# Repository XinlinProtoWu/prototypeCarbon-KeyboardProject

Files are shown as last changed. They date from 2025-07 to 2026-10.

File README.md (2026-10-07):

# Prototype Carbon — A Custom 65% Mechanical Keyboard

A 65% mechanical keyboard I designed, built, and programmed from scratch.
It has 67 keys, split 3u spacebars, a gasket-mounted acrylic case, hot-swap sockets,
per-key RGB, and QMK firmware with VIA remapping.

**Watch the demo:**

Watch Video (https://www.youtube.com/watch?v=WMbd48JGXQo&ab_channel=XinlinWu)

---

## Project Overview

Prototype Carbon went through the whole design process, from requirements and a rough
architecture down to the schematic, board layout, case, firmware, and finally a working keyboard.

| System | Spec |
|---|---|
| Layout | 65%, 67 keys, standard stagger |
| Spacebars | 2x 3u split spacebars |
| Switch matrix | 5 rows x 15 columns, COL2ROW diodes |
| MCU | ATmega32u4-AU (QFP-44) at 16 MHz |
| Connectivity | USB-C |
| Firmware | QMK with VIA remapping enabled |
| RGB | 75x WS2812B LEDs (67 per-key + 8 underglow) on pin B0 |
| Switches | 67x Kailh hot-swap sockets |
| Mounting | Gasket mount, layered acrylic shell |
| Diodes | 67x SOD-123F |

---

## Design Requirements

| ID | Requirement |
|---|---|
| R1 | 65% form factor with a dedicated arrow cluster and nav column |
| R2 | Two 3u split spacebars for extra thumb inputs |
| R3 | Fully hot-swappable, so switches can be changed without soldering |
| R4 | Per-key RGB backlighting plus underglow on a single data line |
| R5 | USB-C connectivity and standard HID, no drivers needed |
| R6 | Keys remappable live through VIA |
| R7 | A soft, gasket-mounted typing feel in a stacked acrylic case |
| R8 | A function layer with F1–F12 and RGB controls |

---

## System Architecture

```
+--------------------------------------------------------------------------+
|                                HOST (PC)                                  |
|                         USB-C  /  HID keyboard                            |
+------------------------------------+-------------------------------------+
                                     | USB
+------------------------------------v-------------------------------------+
|  ATmega32u4-AU at 16 MHz            +-----------------------------------+ |
|  QMK firmware (+VIA)                |  RGB matrix (WS2812B, pin B0)     | |
|                                     |  75 LEDs: 67 per-key + 8 underglow| |
|  +---------------+                  +-----------------------------------+ |
|  | 5x15 switch   |                                                     | |
|  | matrix        |  <- 67x Kailh hot-swap sockets + SOD-123F diodes    | |
|  | (COL2ROW)     |                                                     | |
|  +---------------+                                                     | |
|   (EC11 rotary encoder is routed but not usable, see Known Issues)      | |
+--------------------------------------------------------------------------+
```

**Signal flow:** a key press closes a switch in the matrix, the MCU scans the rows and columns
(COL2ROW), QMK debounces the input and maps it to a keycode, then sends a USB HID report to the
host. At the same time, QMK's RGB matrix drives all 75 WS2812B LEDs over a single data pin.

---

## Systems Design Process

This was an iterative process. Each step produced the files that fed into the next one, and
testing fed problems back into earlier steps.

```mermaid
flowchart TD
    A[1. Requirements & Concept] --> B[2. Electrical Design / Schematic]
    B --> C[3. PCB Design & Layout]
    A --> D[4. Mechanical Design / Case, Plate, Gasket]
    C --> E[5. Firmware Design / QMK & VIA]
    D --> F[6. Integration & Assembly]
    E --> F
    F --> G[7. Verification & Testing]
    G -->|issues found| B
    G --> H[8. Iteration & Lessons Learned]
```

### Phase 1 — Requirements & Concept

I started with the layout, deciding where every key sits and how big the modifiers and spacebars
should be, before committing to any hardware.

- **Layout spec (KLE):** [layout.txt](./layout.txt) — the 67-key 65% layout with split 3u spacebars
- **Layout model:** [protocarbon.json](./protocarbon.json) — keyboard-layout-editor JSON
- **Keymap matrix:** [prototypeCarbonVIA.json](./prototypeCarbonVIA.json) — the 5x15 matrix and VIA layout

### Phase 2 — Electrical Design (Schematic)

Next came the schematic: an ATmega32u4 with a 16 MHz crystal, USB-C, the COL2ROW switch matrix,
the per-key RGB chain, and the usual decoupling caps.

- **Schematic:** [SCH_prototypeCarbon_2025-07-03.json](./SCH_prototypeCarbon_2025-07-03.json)
- **Bill of materials:** [BOM_prototypeCarbon_2025-07-03.csv](./BOM_prototypeCarbon_2025-07-03.csv)
- **Shopping list:** [prototypeCarbonShoppingList - BOM_prototypeCarbon_2025-07-03.csv](./prototypeCarbonShoppingList%20-%20BOM_prototypeCarbon_2025-07-03.csv)

### Phase 3 — PCB Design & Layout

Then I routed the board, placed the hot-swap sockets and per-key LEDs, and exported the files
needed for manufacturing.

- **PCB design:** [PCB_PCB_prototypeCarbon_2025-07-03.json](./PCB_PCB_prototypeCarbon_2025-07-03.json)
- **PCB outline (DXF):** [PCB_prototypeCarbon_2025-07-05.dxf](./PCB_prototypeCarbon_2025-07-05.dxf)
- **PCB outline, revised:** [PCB_prototypeCarbon_2025-07-05 gai.dxf](./PCB_prototypeCarbon_2025-07-05%20gai.dxf)
- **Gerber files (fabrication):** [Gerber_prototypeCarbon_PCB_prototypeCarbon_2025-07-03.zip](./Gerber_prototypeCarbon_PCB_prototypeCarbon_2025-07-03.zip)

### Phase 4 — Mechanical Design (Case, Plate & Gasket)

The case came next: a gasket-mounted stack of laser-cut acrylic layers sized to match the PCB.

- **Acrylic shell stack (DWG):** [prototypeCarbonGasketShell.dwg](./prototypeCarbonGasketShell.dwg)
- **Acrylic plates (DWG):** [prototypeCarbonAcrylicPlates.dwg](./prototypeCarbonAcrylicPlates.dwg)
- **Stack drawing (DWG):** [stack.dwg](./stack.dwg)
- **Switch plate (DWG):** [plate1.dwg](./plate1.dwg) / (DXF) [plate1.dxf](./plate1.dxf)
- **Gasket (DWG):** [gasket.dwg](./gasket.dwg) / [prototypeCarbonGasket.dwg](./prototypeCarbonGasket.dwg)

### Phase 5 — Firmware Design (QMK + VIA)

With the hardware designed, I wrote the QMK firmware: matrix pins, COL2ROW, the WS2812B RGB
matrix, and a function layer, plus VIA support so keys can be remapped without reflashing.

- **Firmware directory:** [qmk_firmware/keyboards/prototypeCarbon](./qmk_firmware/keyboards/prototypeCarbon)
- **Hardware config:** `config.h`, `rules.mk` (matrix pins, RGB, VIA)
- **Keymaps:** `keymaps/default/keymap.c` and `keymaps/VIA/keymap.c`
- **Layer-2 keybind reference:** [layer2keybind.JPG](./layer2keybind.JPG)

### Phase 6 — Integration & Assembly

Assembly meant soldering the SMD parts (MCU, diodes, caps, LEDs, USB-C), snapping in the hot-swap
sockets, and bolting the case together.

- 24x M2 x 4 mm screws
- 12x M2 x 14 mm double-headed copper standoffs

### Phase 7 — Verification & Testing

I flashed the firmware and checked the whole system end to end.

- Passed: key matrix scan across all 67 keys
- Passed: RGB chain (67 per-key + 8 underglow) on a single data pin
- Passed: VIA detection and live remapping
- Failed: EC11 rotary encoder — see Known Issues below

### Phase 8 — Iteration & Lessons Learned

Testing caught a routing mistake on the rotary encoder (EC11 wired to AREF). I documented it,
isolated it, and worked around it. A proper fix would need a schematic and PCB re-spin.

---

## How to Build This Keyboard

1. **Print the PCB** — [Gerber_prototypeCarbon_PCB_prototypeCarbon_2025-07-03.zip](./Gerber_prototypeCarbon_PCB_prototypeCarbon_2025-07-03.zip)
2. **Print the case and plates** — [prototypeCarbonGasketShell.dwg](./prototypeCarbonGasketShell.dwg) and [gasket.dwg](./gasket.dwg)
3. **Order the electrical components** — [BOM_prototypeCarbon_2025-07-03.csv](./BOM_prototypeCarbon_2025-07-03.csv), plus:
   - 1x ATmega32u4AU microcontroller
   - 67x Kailh hot-swap sockets
   - 67x 6028RGBC-WS2812B RGB LEDs
4. **Buy the keyboard parts** — 67x switches, 67x keycaps, 24x M2 x 4 mm screws, 12x M2 x 14 mm standoffs
5. **Assemble** — keep the PCB in front of you while soldering, and double-check the LED and MCU pin orientation
6. **Compile the firmware** — use QMK_MSYS in [qmk_firmware/keyboards/prototypeCarbon](./qmk_firmware/keyboards/prototypeCarbon)
7. **Flash** — upload the compiled firmware with QMK Toolbox
8. **Configure in VIA** — load [prototypeCarbonVIA.json](./prototypeCarbonVIA.json) to view or remap the keymap

---

## Known Issues

**EC11 rotary encoder pin error**

The EC11 rotary encoder is not wired correctly on the PCB — one of its pins connects to the AREF
pin on the ATmega32u4AU. Don't install it unless you fix this in hardware first; use a regular
hot-swap socket in its place for now.

---

## Repository Structure

| Path | Purpose |
|---|---|
| `layout.txt` / `protocarbon.json` | Layout concept (KLE) |
| `SCH_prototypeCarbon_2025-07-03.json` | Schematic |
| `PCB_PCB_prototypeCarbon_2025-07-03.json` | PCB layout |
| `Gerber_*.zip` | PCB fabrication files |
| `*.dwg` / `*.dxf` | Case, plates, gasket (mechanical) |
| `BOM_*.csv` | Bill of materials |
| `prototypeCarbonVIA.json` | VIA keymap definition |
| `qmk_firmware/keyboards/prototypeCarbon/` | QMK firmware |

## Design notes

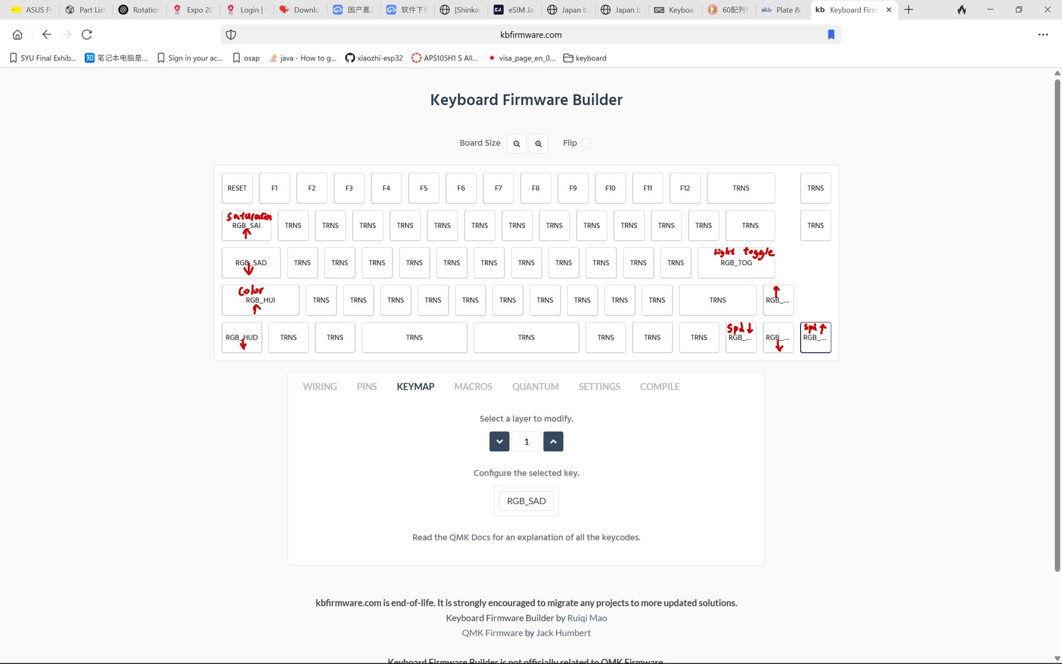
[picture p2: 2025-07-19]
layer2keybind.JPG

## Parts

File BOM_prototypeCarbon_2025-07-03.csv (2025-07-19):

ID | Name | Designator | Footprint | Quantity
1 | 1uF | C1 | C0805 | 1
2 | 20pF | C2,C3 | C0805 | 2
3 | 100nF | C9,C10,C11,C12,C13,C14,C15,C16,C17,C18,C19,C20,C21,C22,C23,C24,C25,C26,C27,C28,C29,C30,C31,C32,C33,C34,C35,C36,C37,C38,C39,C40,C41,C42,C43,C44,C45,C46,C47,C48,C49,C50,C51,C52,C53,C54,C55,C56,C57,C58,C59,C60,C61,C62,C63,C64,C65,C66,C67,C68,C69,C70,C71,C72,C73,C74,C75,C76,C77,C78,C79,C80,C81,C82,C84,C7,C6,C5,C4 | C0805 | 79
4 | SOD4002-SH | D1,D2,D3,D4,D5,D6,D7,D8,D9,D10,D11,D12,D13,D14,D15,D16,D17,D18,D19,D20,D21,D22,D23,D24,D25,D26,D27,D28,D29,D30,D31,D32,D33,D34,D35,D36,D37,D38,D39,D40,D41,D42,D43,D44,D45,D46,D47,D48,D49,D50,D51,D52,D53,D54,D55,D56,D57,D58,D59,D60,D61,D62,D63,D64,D65,D66,D67 | SOD-123F_L2.8-W1.8-LS3.7-RD | 67
5 | Switch3x4x2 | KEY1 | SW-SMD_L4.0-W2.9-LS5.0 | 1
6 | 10kΩ | R1,R2 | R0805 | 2
7 | 22Ω | R3,R4 | R0805 | 2
8 | ATMEGA32U4-AU | U1 | QFP-44_L10.0-W10.0-P0.80-LS13.2-BL | 1
9 | 16MHz | X1 | OSC-SMD_2P-L5.0-W3.2 | 1
10 | WS2812B-3528 | U2,U3,U4,U5,U6,U7,U8,U9 | WS2812B-3528 | 8
11 | TYPE-C-31-M-12 | USBC1 | USB-C_SMD-TYPE-C-31-M-12 | 1
12 | 470nF | C8 | C0805 | 1
13 | EC11E15244G1 | SW68 | SW-TH_EC11E15244G1GAI | 1

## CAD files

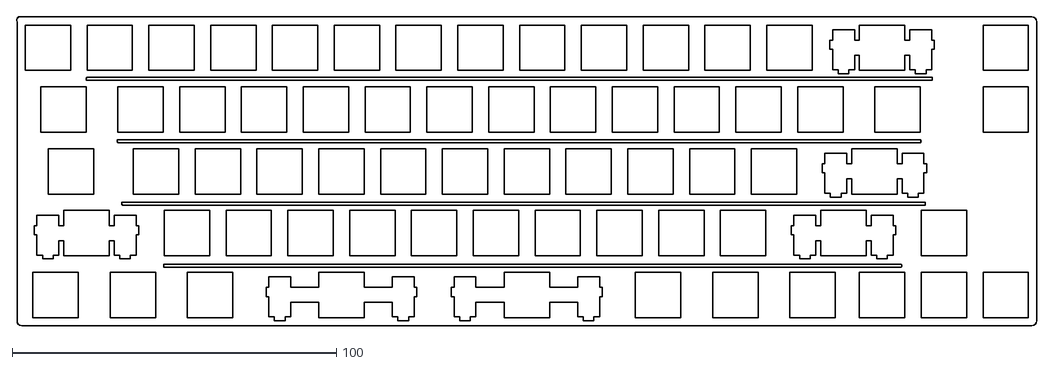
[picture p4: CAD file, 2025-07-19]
plate1.dxf
314.5 x 95.5

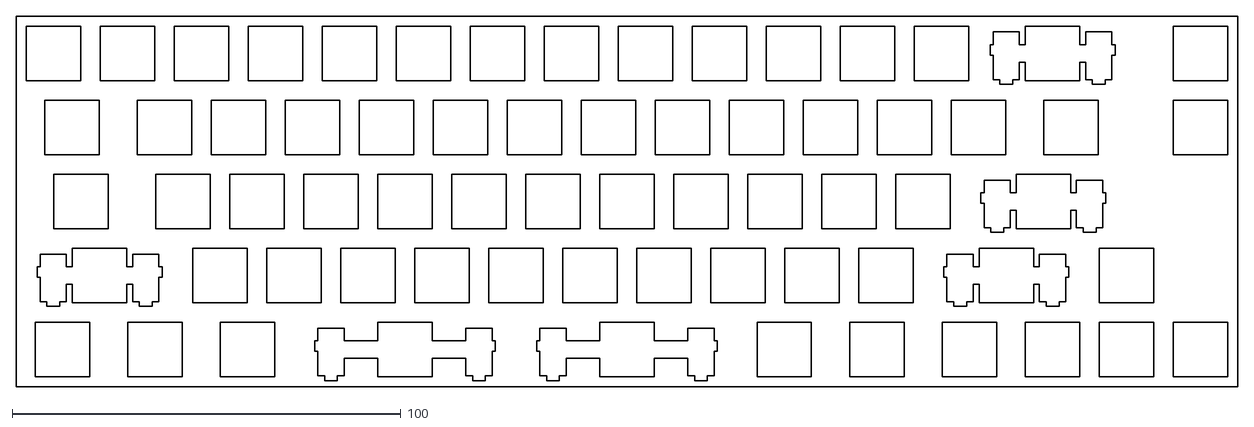
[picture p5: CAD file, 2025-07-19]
plate.dxf
314.3 x 95.2

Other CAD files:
prototypeCarbonGasket.dwg
PCB_prototypeCarbon_2025-07-05 gai.dxf
stack.dwg
plate1_recover.dwg
gasket.dwg
PCB_prototypeCarbon_2025-07-05.dxf
prototypeCarbonAcrylicPlates.dwg
prototypeCarbonGasketShell.dwg
plate1.dwg

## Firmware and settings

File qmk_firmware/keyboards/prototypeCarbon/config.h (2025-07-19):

#ifndef CONFIG_H
#define CONFIG_H

#include "config_common.h"

/* USB Device descriptor parameter */
#define VENDOR_ID       0xFE66
#define PRODUCT_ID      0x6060
#define DEVICE_VER      0x0001
#define MANUFACTURER    xinLinWu
#define PRODUCT         prototypeCarbon
#define DESCRIPTION     sixtyPercent

/* key matrix size */
#define MATRIX_ROWS 5
#define MATRIX_COLS 15

/* key matrix pins */
#define MATRIX_ROW_PINS { B7, D0, D1, D2, B3 }
#define MATRIX_COL_PINS { B2, D5, D3, D6, D7, B4, C7, B6, C6, B5, F6, F7, F5, F4, F1 }
#define UNUSED_PINS

/* COL2ROW or ROW2COL */
#define DIODE_DIRECTION COL2ROW

/* Set 0 if debouncing isn't needed */
#define DEBOUNCING_DELAY 5

/* Mechanical locking support. Use KC_LCAP, KC_LNUM or KC_LSCR instead in keymap */
#define LOCKING_SUPPORT_ENABLE

/* Locking resynchronize hack */
#define LOCKING_RESYNC_ENABLE

/* key combination for command */
#define IS_COMMAND() ( \
    keyboard_report->mods == (MOD_BIT(KC_LSHIFT) | MOD_BIT(KC_RSHIFT)) \
)

/* prevent stuck modifiers */
#define PREVENT_STUCK_MODIFIERS


// RGB matrix definition
#ifdef RGB_MATRIX_ENABLE

#define RGB_DI_PIN B0
#define RGBLED_NUM 75
#define DRIVER_LED_TOTAL RGBLED_NUM
#define RGB_MATRIX_KEYPRESSES
#define RGB_DISABLE_WHEN_USB_SUSPENDED false
#define RGB_MATRIX_CENTER {112, 32}

#endif

#endif
